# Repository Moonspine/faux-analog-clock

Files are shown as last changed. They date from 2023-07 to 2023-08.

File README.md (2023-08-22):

# Faux Analog Clock

An analog clock composed entirely of LEDs

The build should be fairly self-explanatory. A KiCad 6 schematic and board layout are included in `Board\`  
Additionally, `Board\Faux Analog Clock Gerber.zip` is a ready-to-go Gerber plot of the board which can be sent directly to the PCB manufacturer of your choice.  
LED resistor values are mere suggestions, and you should experiment on a breadboard to see what works well with your chosen LEDs.  

The following photos show the clock operating with its "Fill 2" (F2) display mode active:  
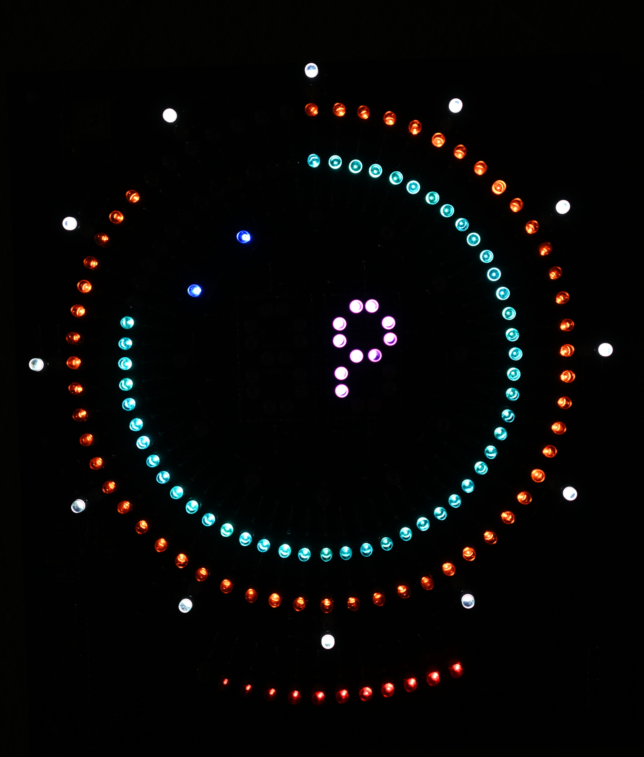
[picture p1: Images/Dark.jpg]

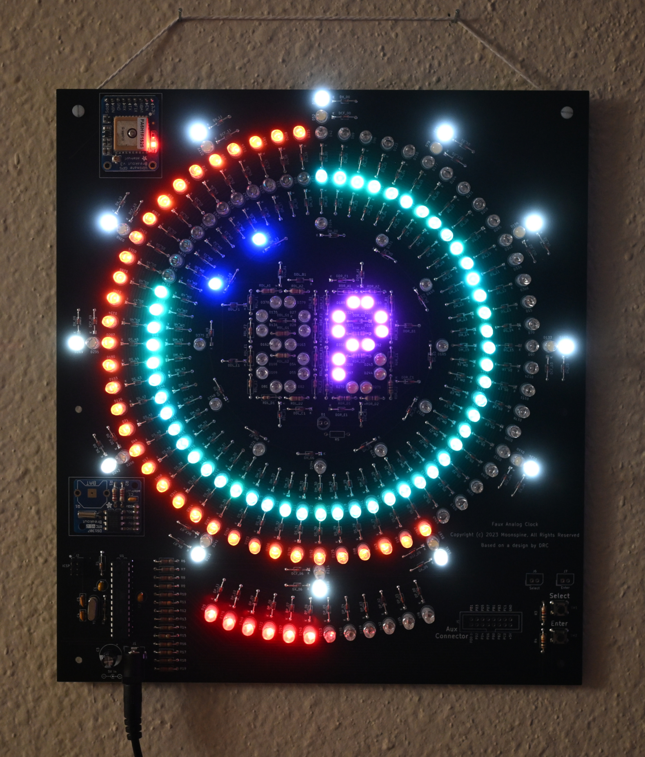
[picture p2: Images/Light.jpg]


# Debugging the build

In order to facilitate easier debugging during the build process, two LED tests are easily accessible on startup.  

If you press and hold "Select" as you turn the clock on, it will boot in "LED test 1" mode.  
This mode displays all LEDs at full brightness to help track down bad solder joints, backwards diodes, etc.  
This test mode is accessible via the utilities menu after startup. Press any key to resume the normal boot sequence.  

If you press and hold "Enter" as you turn the clock on, it will boot in "LED test 2" mode.  
This mode displays each LED in sequence. This is useful for tracking down solder bridges and confirming proper clock operation.  
This test mode is also accessible via the utilities menu after startup. Press any key to resume the normal boot sequence.  

# Using the menu

Press "Select" or "Enter" to enter the menu.  
Subsequent presses of "Select" will advance to different menu options.  
Pressing "Enter" will choose a menu option (either changing a setting or opening a submenu.)  
Pressing and holding "Select" for the amount of time defined by MENU_BACK_BUTTON_LONG_PRESS_MS will return to the previous menu (or close the menu if at the top menu.)  
If no buttons are pressed for MENU_TIMEOUT_MS milliseconds, the menu will close on its own.

## Main menu options
- tZ (72) = Timezone
- dS (d5) = Daylight Saving Time
- FE (FE) = Face effects (Clock face ring effects)
- Fd (Fd) = Fade effects
- br (br) = Brightness
- nb (nb) = Night brightness (multiplied by brightness)
- dY (d4) = Display mode
- Pd (Pd) = Pendulum period
- UT (U7) = Utilities

## Timezone menu

In this menu, you can select the timezone offset of the clock, in whole hour increments.  
These values are displayed in hexadecimal (sorry, 7-segment displays) ranging from "-C" (-12 hours) to "E" (+14 hours)

## Daylight Saving Time menu

In this menu, you can set whether DST is in effect ("Y") or not ("n")

## Face Effects menu

This menu controls the face edge lighting.
- "on" = Face effects are turned on (fading between inner and outer at sunrise/sunset)
- "ou" = Face effects are turned off, always light outer clock face ring
- "in" = Face effects are turned off, always light inner clock face ring
- "bo" = Face effects are turned off, always light both clock face rings

## Fade Effects menu

This menu turns the LED intensity fade effects on ("Y") or off ("n")

## Brightness menu

This menu controls overall clock LED brightness from 1 (dimmest) to 10 (brightest).

## Night Brightness menu

This menu controls overall clock LED brightness at night (from 6 PM to 6 AM) from 1 (dimmest) to 10 (brightest).  
This value is multiplied by the overall clock brightness, making it effectively a scalar for clock brightness that's only applied at night.

## Display mode menu

This menu allows you to select between different clock face display modes.
- "An" = Analog mode. This is the classic analog clock face, showing one LED for hours, one for minutes, and one for seconds.
- "bn" = Binary mode. This mode displays H/M/S in binary. The LSb is at 12 o'clock, and the bits are displayed in clockwise order from there. The hours use 3 LEDs per bit (displaying a 4-bit number in total), and the minutes and seconds each use 10 LEDs per bit (displaying a 6-bit number).
- "F1" = Fill mode 1. This mode fills the hour/minute/second rings as time progresses, clearing them at the turn of the minute/hour.
- "F2" = Fill mode 2. This mode fills the hour/minute/second rings on even minutes/hours/AM (respectively), and empties the rings on odd mintes/hours/PM.
- "In" = Inverted analog mode. This is the same as analog move, except that the LEDs are inverted.

## Pendulum period menu

This menu allows you to set the period of the pendulum.
- "FA" = Fast (1 second)
- "SL" = Slow (2 seconds)

## Utilities menu

This menu includes some useful utilities for testing your clock build.
- "RS" ("r5") = Reset the current time using the GPS
- "L1"        = Run LED test 1 (light all LEDs at max intensity) (press any button to end)
- "L2"        = Run LED test 2 (light LEDs at max intensity sequentially) (press any button to end)

# Customizing the clock

## Faux_Analog_Clock.ino

At the top of `Firmware/Faux_Analog_Clock/Faux_Analog_Clock.ino`, you can find many constants defined which alter the behavior of the clock.

You can change the fade animation rate by modifying variables in the "Animation timing variables" section.
- CLOCK_ANIM_*_FADE_TIME = The number of microseconds between each time the LEDs fade by 1 unit of intensity (255 is the max LED intensity)

Menu behavior can be configured as well:
- MENU_TIMEOUT_MS                = The number of milliseconds until the menu auto-closes after the last button press.
- MENU_BACK_BUTTON_LONG_PRESS_MS = The number of milliseconds the user must hold the "Select" button to return to the previous menu.

You can also change how often the GPS is used to set the RTC:
- TIMEKEEPER_GPS_TIME_SET_INTERVAL_SECONDS = Seconds in between time resets.

## ClockFace.h

FACE_INNER_HOURLY_BRIGHTNESS and FACE_OUTER_HOURLY_BRIGHTNESS define the brightness of the inner and outer edge rings on a per-hour basis.  
The first entry in each array is the brightness at midnight (hour 0), and the rest of the entries count up from there (1 AM, 2 AM, etc.)

## Pendulum.h
PENDULUM_LED_INDEX contains the LED indices of the pendulum for each individual millisecond following a second tick.  
The default pattern is a sinusoidal pendulum pattern that starts in the center and swings right then left.

## Timekeeper.h

In `Firmware/Faux_Analog_Clock/Timekeeper.h`, commenting out the following line will cause the timekeeper to use an internal millis()-based RTC rather than external RTC hardware:
```
#define USE_HARDWARE_RTC 1
```

You can also modify the amount of time that the timekeeper will attempt to get a fix before forcibly resetting the GPS (the default is 15 minutes):
```
#define GPS_RESET_TIMEOUT_MS 900000
```

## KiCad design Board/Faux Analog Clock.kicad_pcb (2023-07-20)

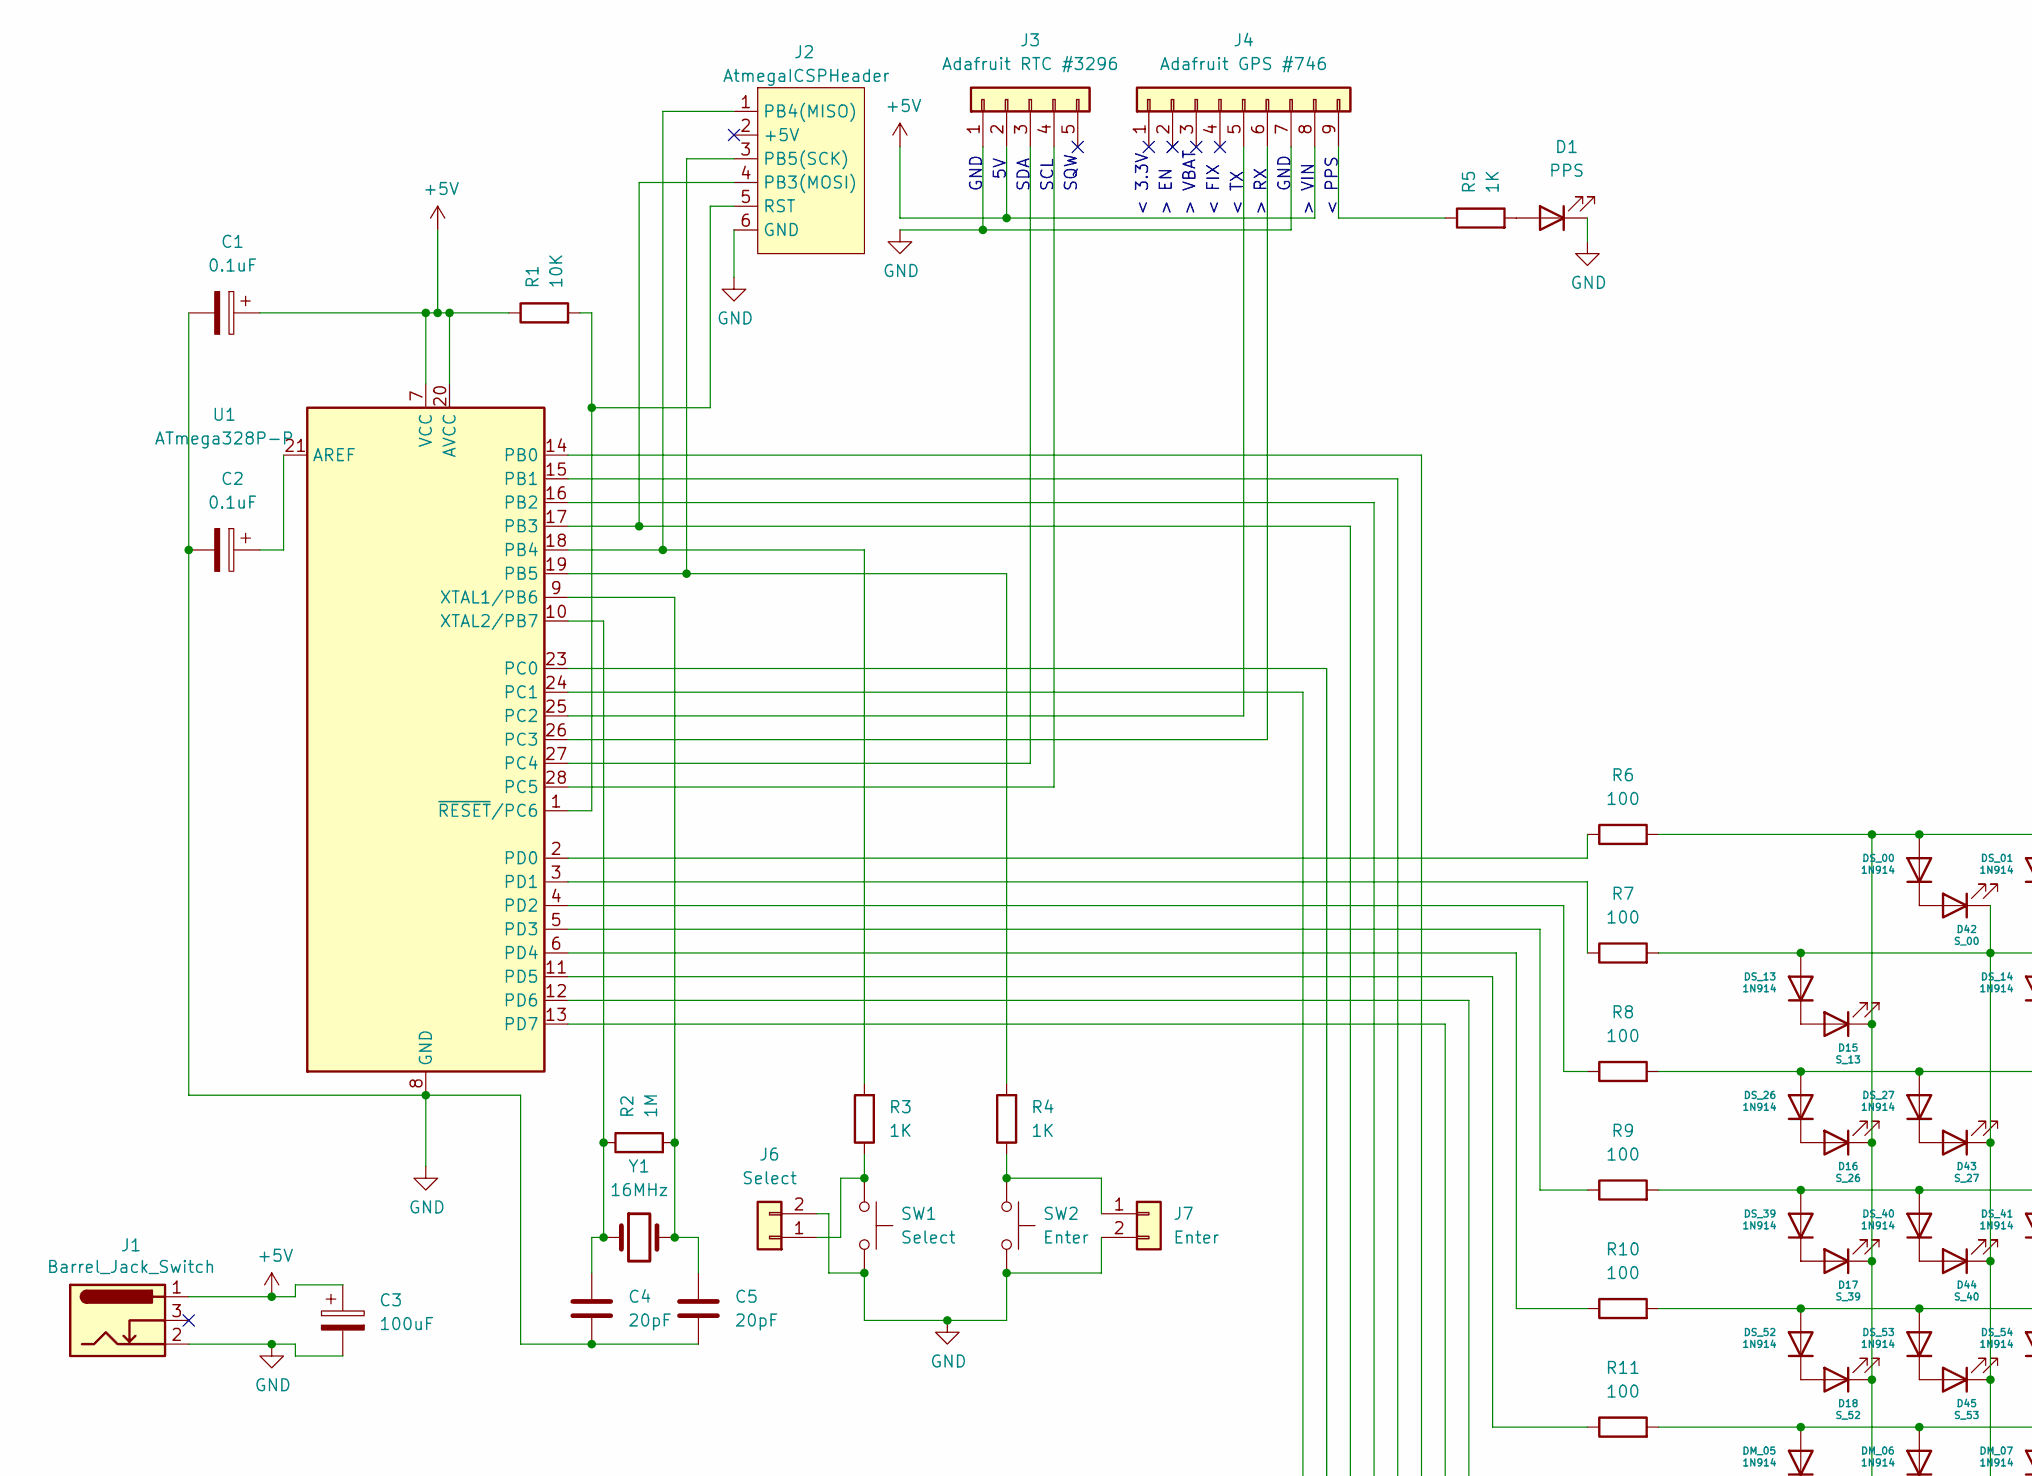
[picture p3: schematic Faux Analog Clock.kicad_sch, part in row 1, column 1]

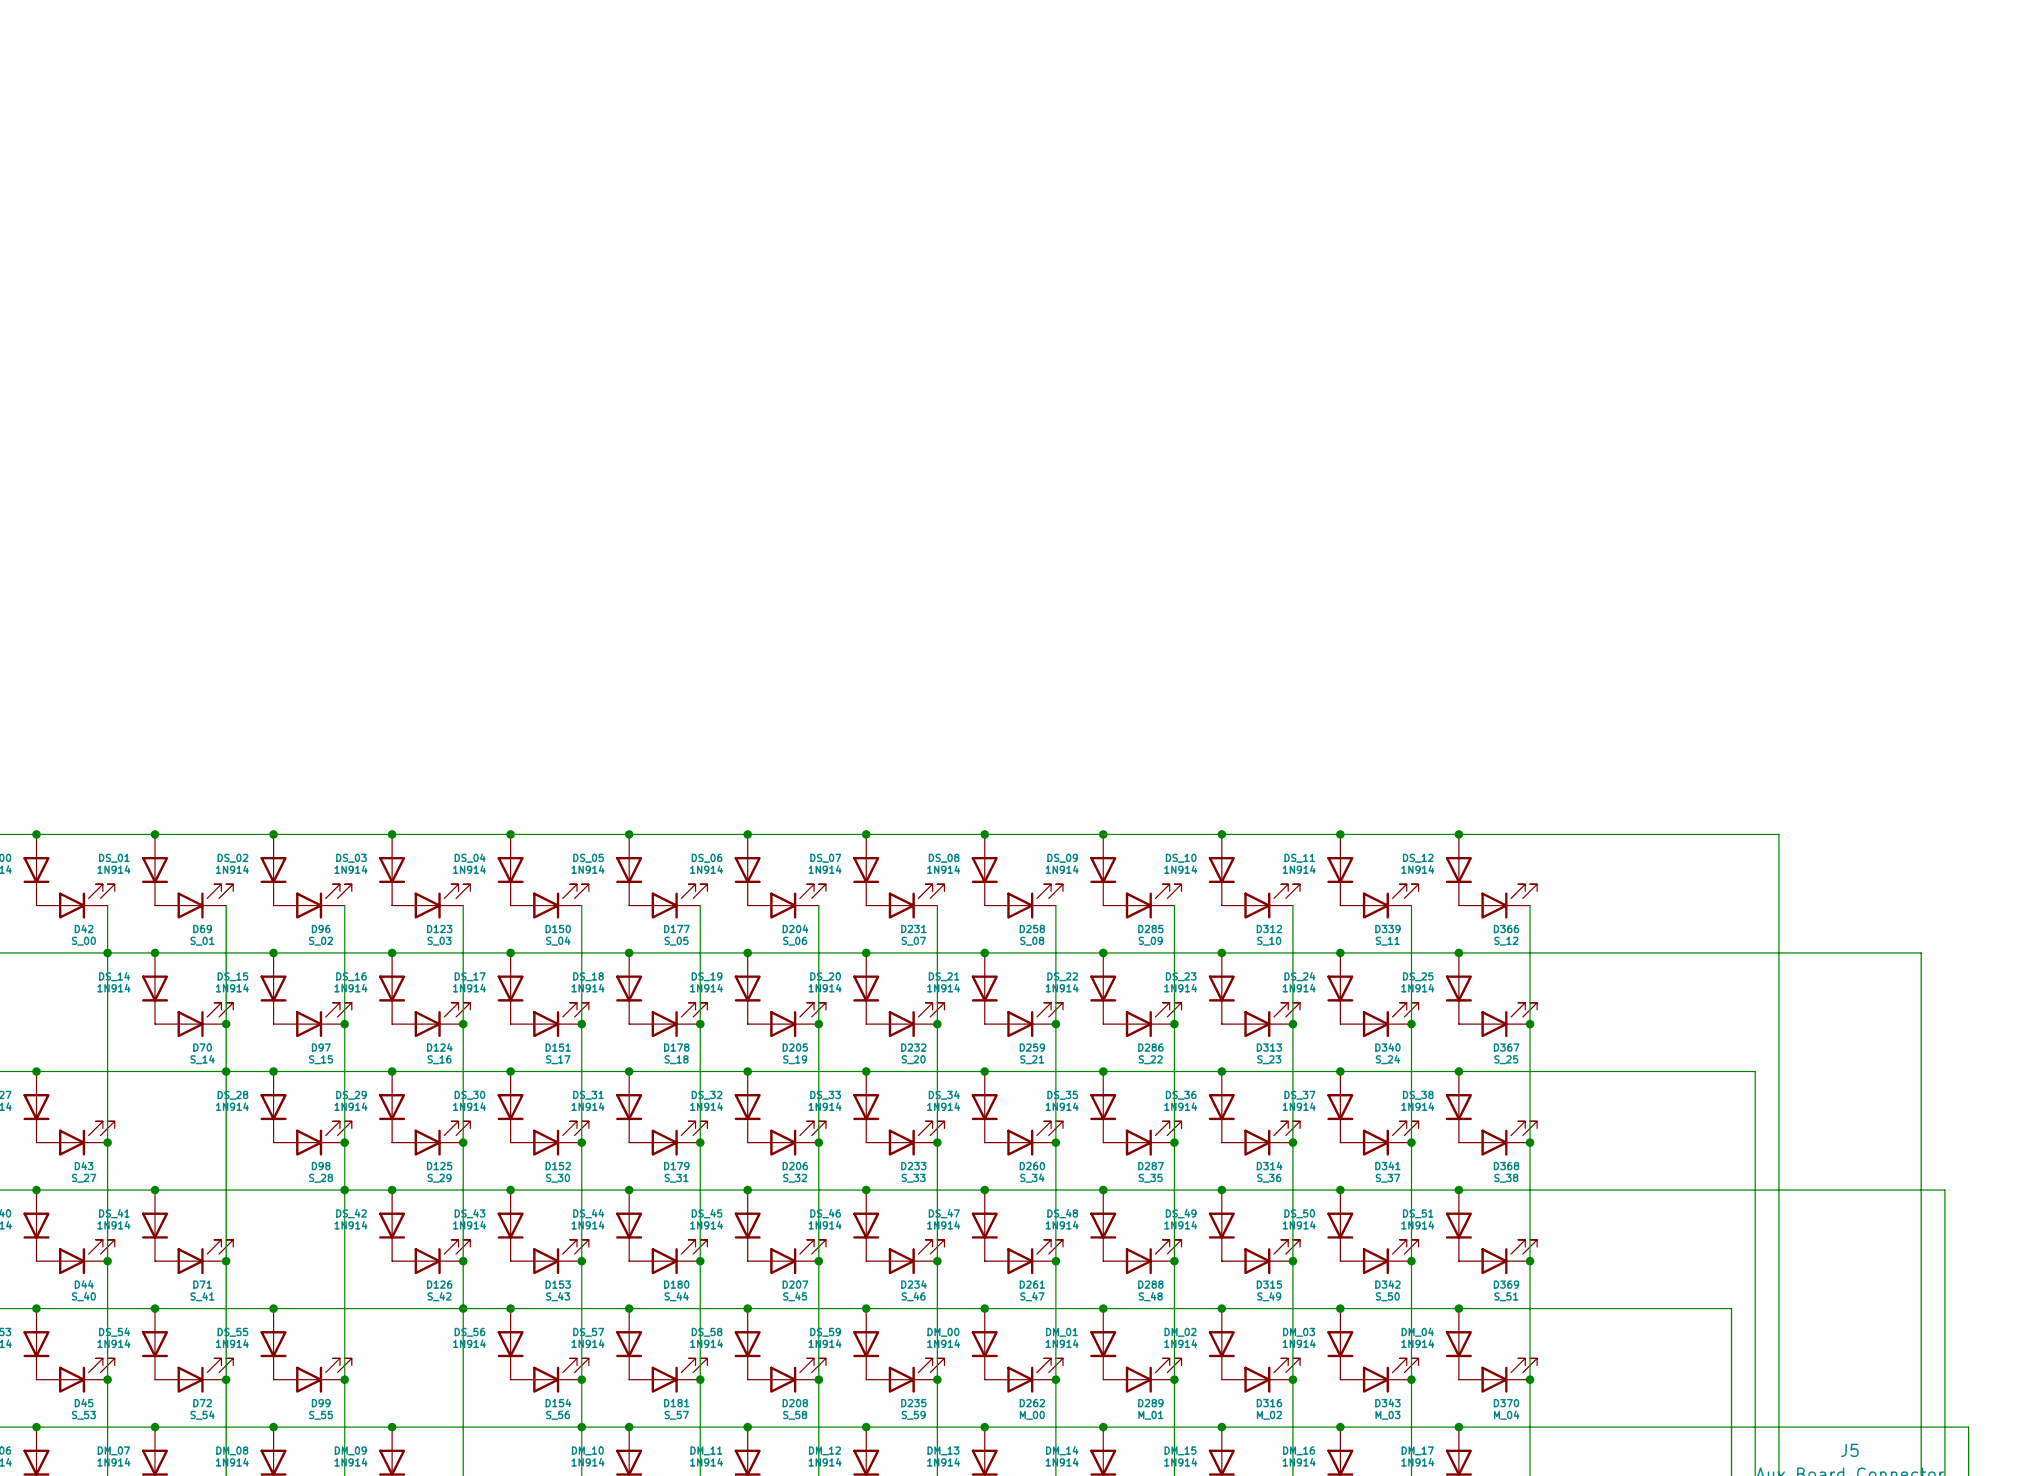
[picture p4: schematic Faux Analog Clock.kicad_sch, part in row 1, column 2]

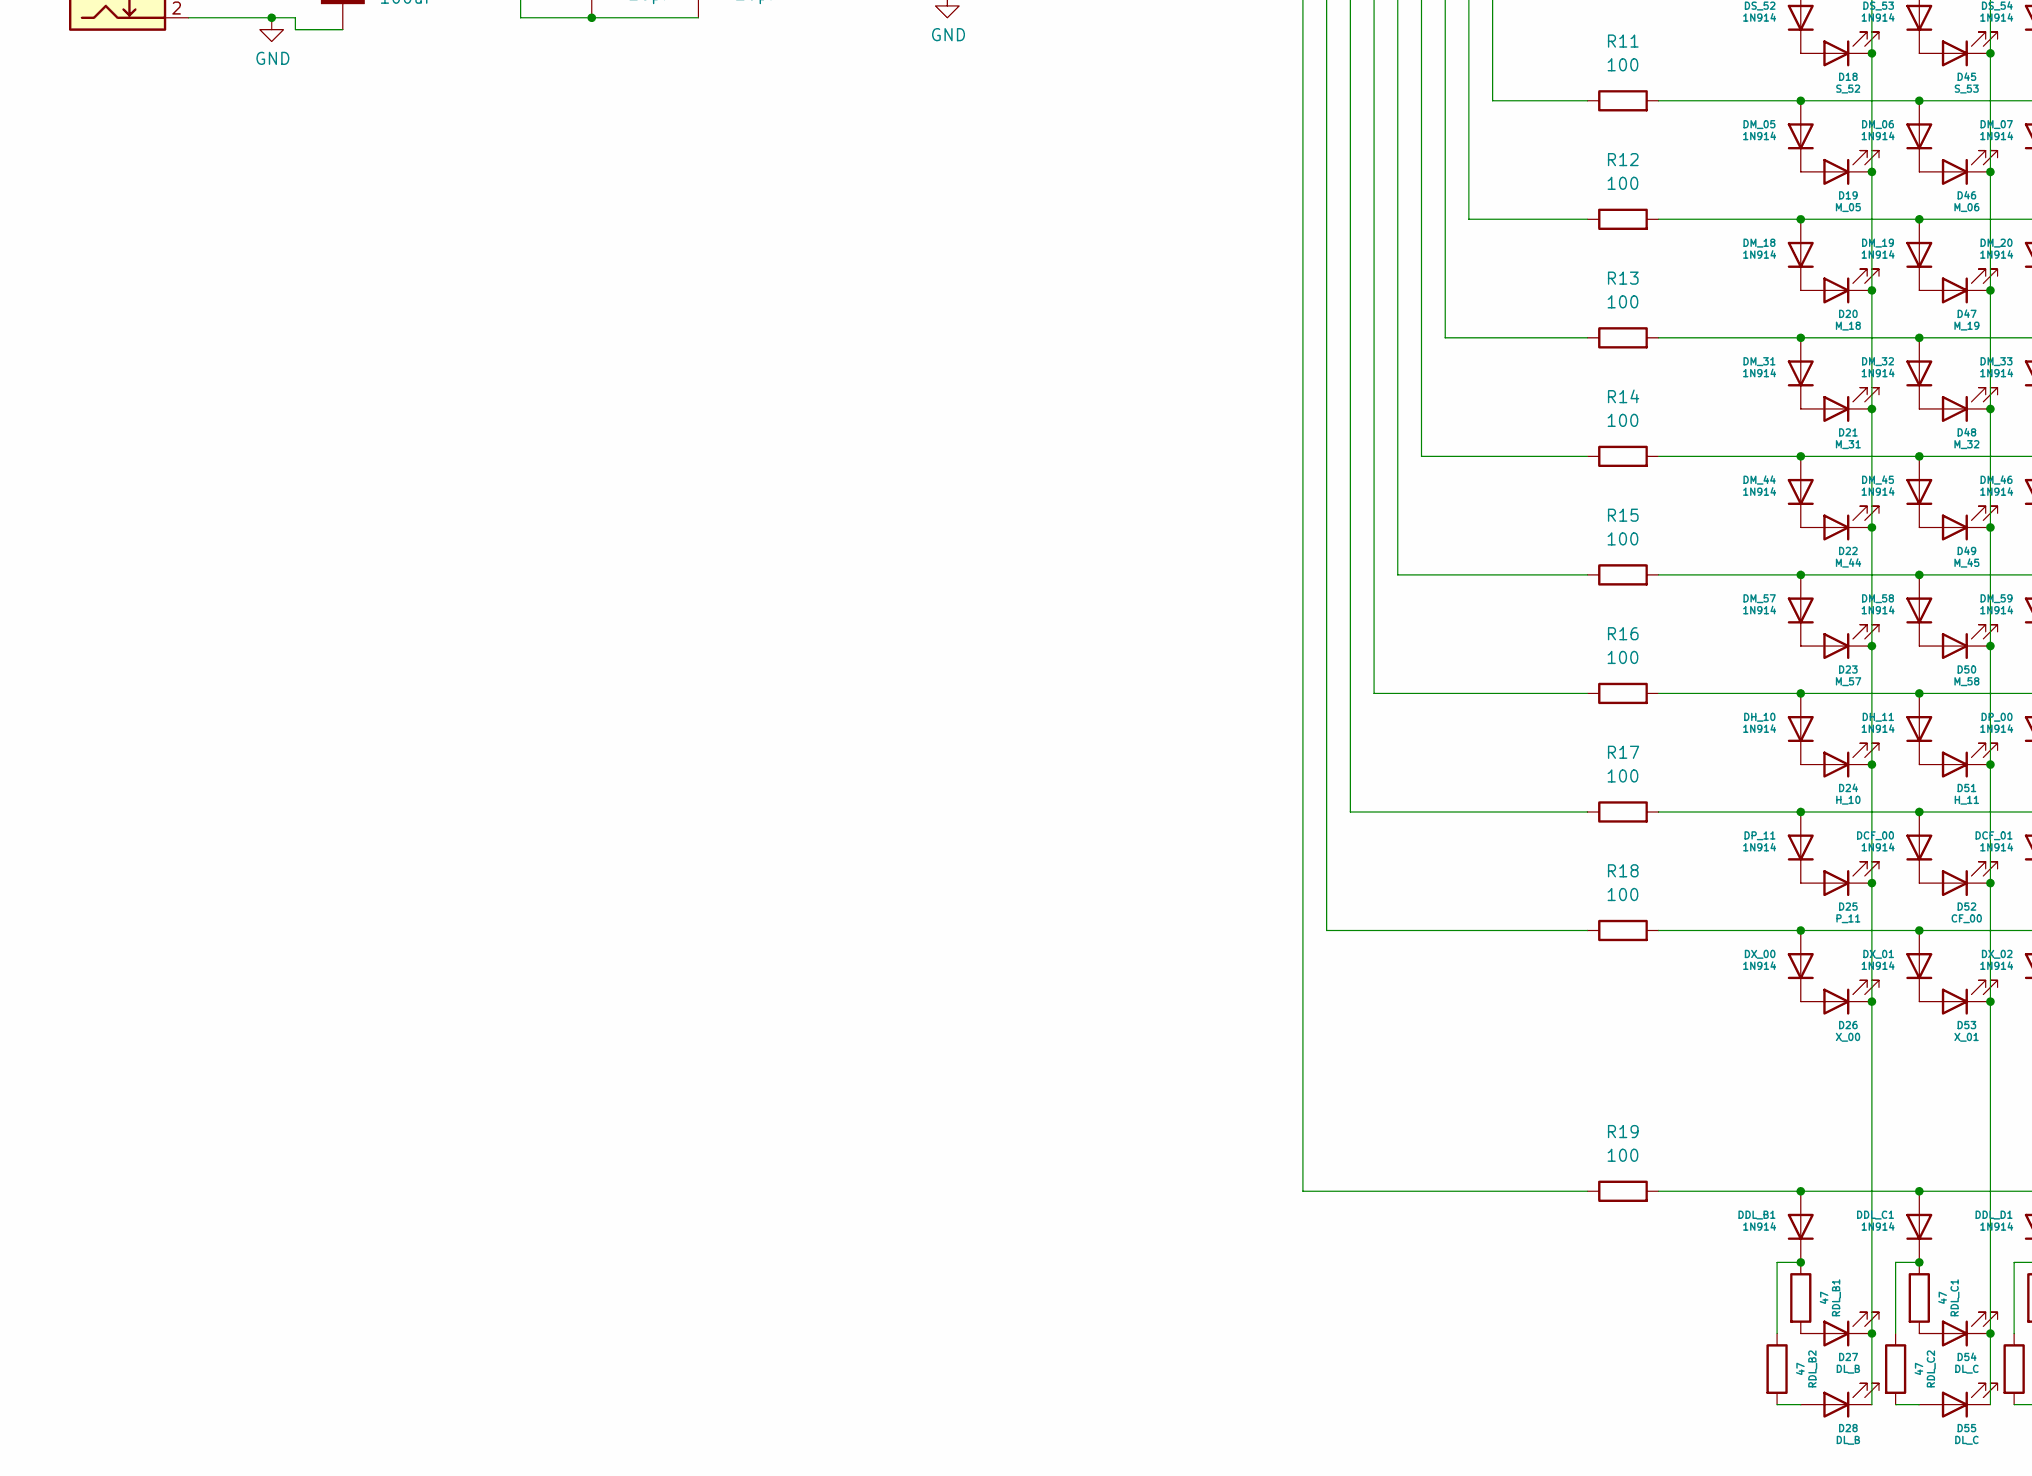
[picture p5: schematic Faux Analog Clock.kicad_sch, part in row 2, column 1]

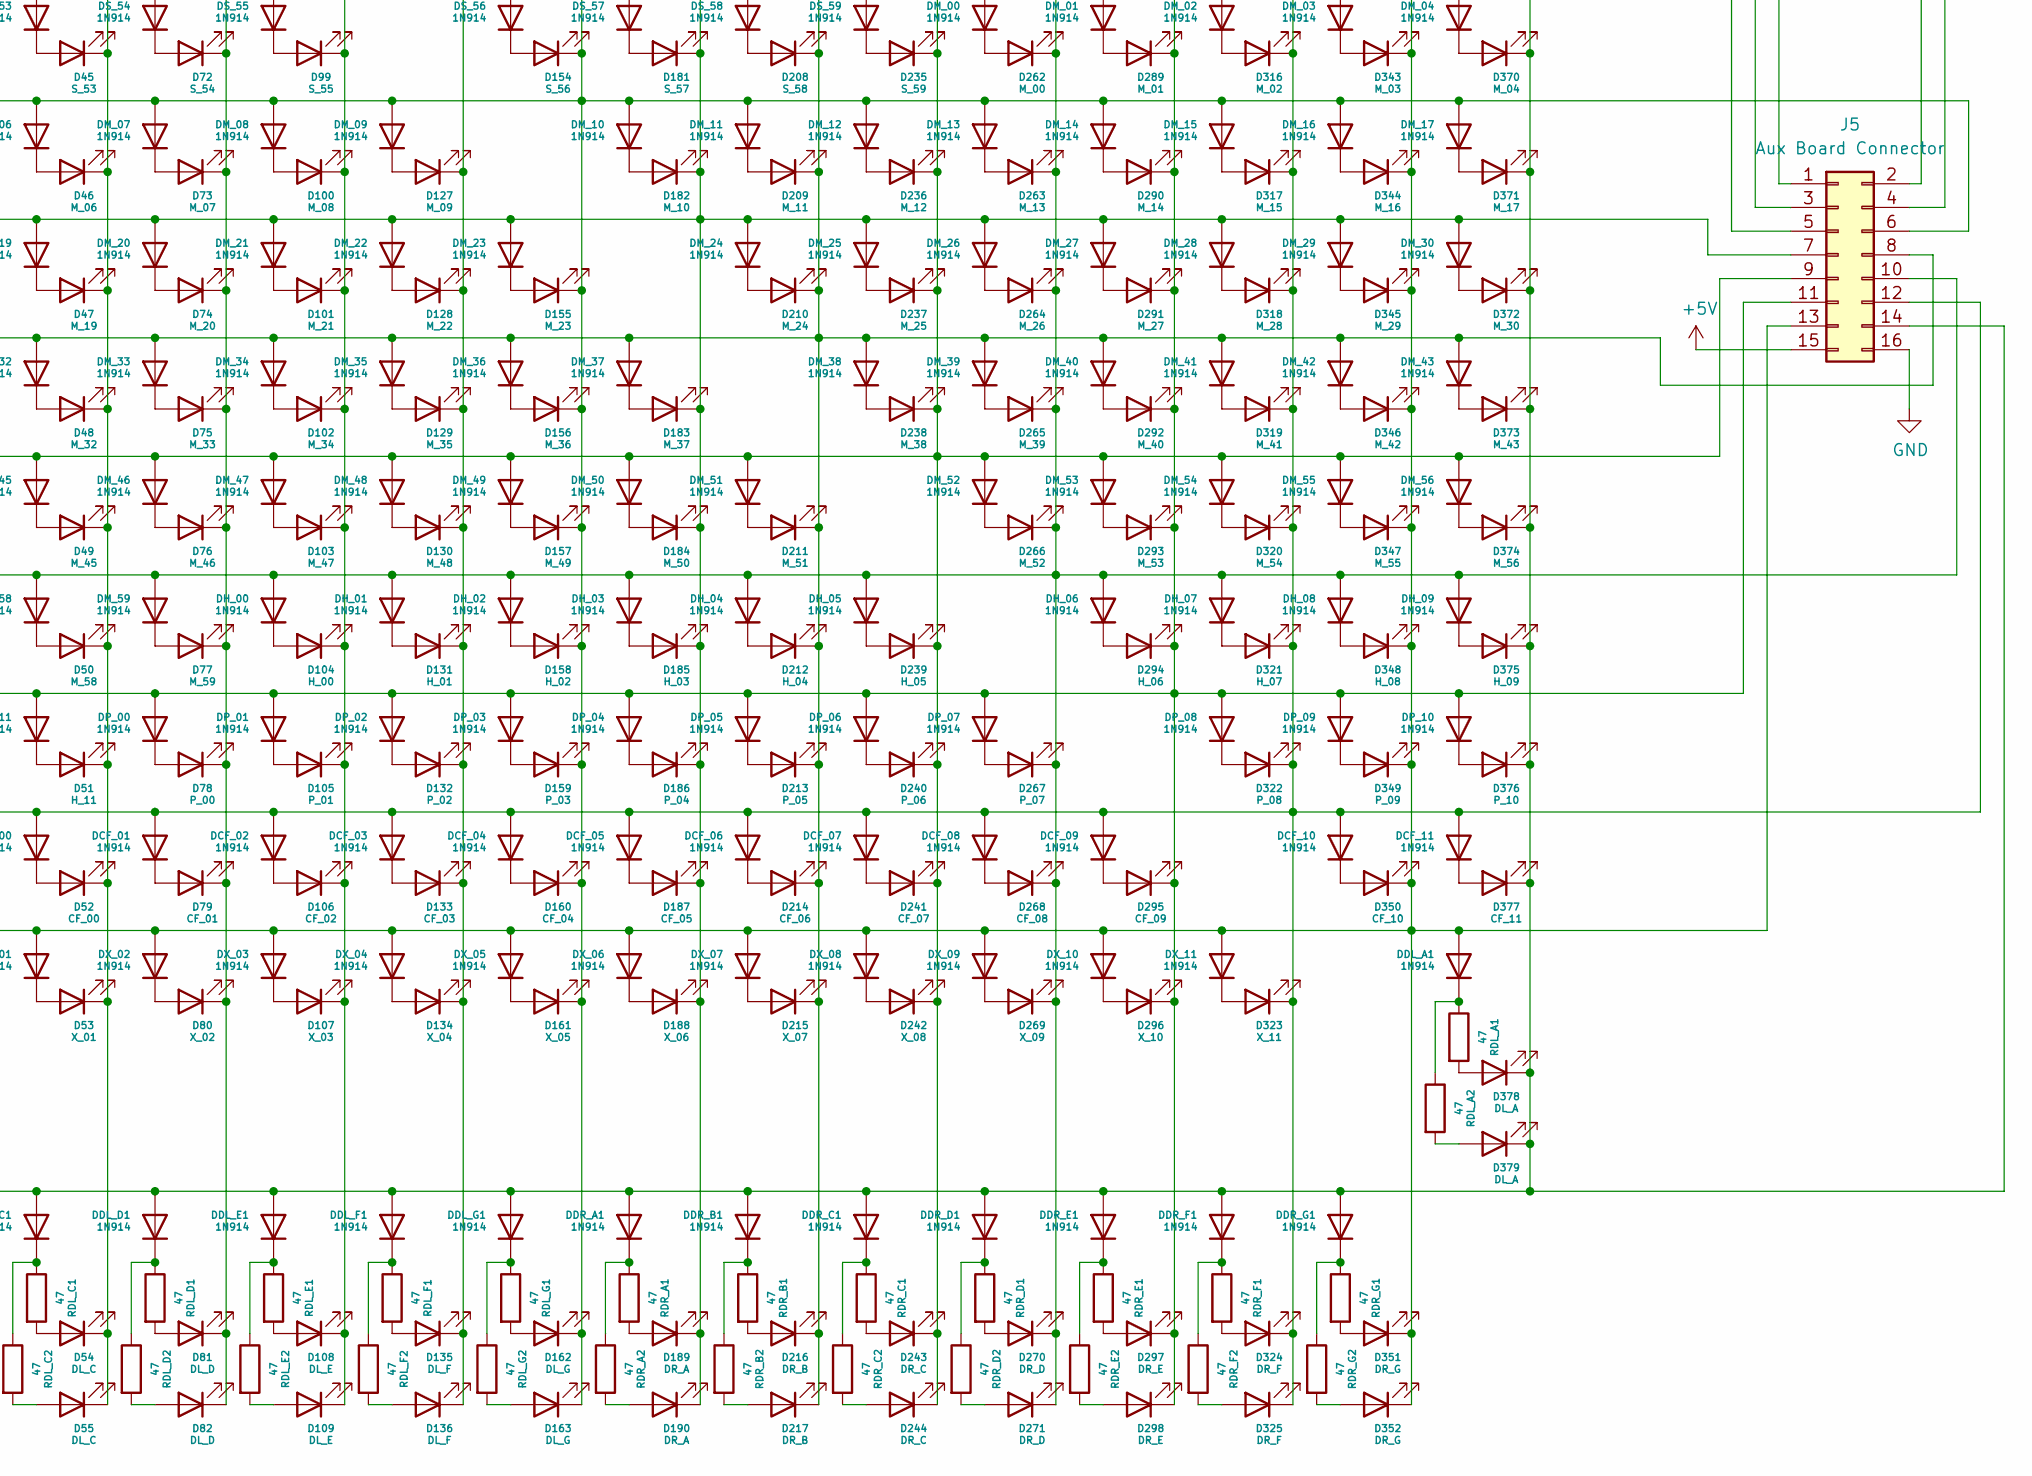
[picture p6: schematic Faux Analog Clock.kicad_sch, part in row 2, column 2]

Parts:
C1, C2: 0.1uF; CP_Radial_Tantal_D5.0mm_P2.50mm
C3: 100uF; CP_Radial_D10.0mm_P3.50mm
C4, C5: 20pF; C_Disc_D5.0mm_W2.5mm_P2.50mm
D1: PPS; LED_D5.0mm
D15: S_13; LED_D5.0mm
D16: S_26; LED_D5.0mm
D17: S_39; LED_D5.0mm
D18: S_52; LED_D5.0mm
D19: M_05; LED_D5.0mm
D20: M_18; LED_D5.0mm
D21: M_31; LED_D5.0mm
D22: M_44; LED_D5.0mm
D23: M_57; LED_D5.0mm
D24: H_10; LED_D5.0mm
D25: P_11; LED_D5.0mm
D26: X_00; LED_D5.0mm
D27, D28: DL_B; LED_D5.0mm
D42: S_00; LED_D5.0mm
D43: S_27; LED_D5.0mm
D44: S_40; LED_D5.0mm
D45: S_53; LED_D5.0mm
D46: M_06; LED_D5.0mm
D47: M_19; LED_D5.0mm
D48: M_32; LED_D5.0mm
D49: M_45; LED_D5.0mm
D50: M_58; LED_D5.0mm
D51: H_11; LED_D5.0mm
D52: CF_00; LED_D5.0mm
D53: X_01; LED_D5.0mm
D54, D55: DL_C; LED_D5.0mm
D69: S_01; LED_D5.0mm
D70: S_14; LED_D5.0mm
D71: S_41; LED_D5.0mm
D72: S_54; LED_D5.0mm
D73: M_07; LED_D5.0mm
D74: M_20; LED_D5.0mm
D75: M_33; LED_D5.0mm
D76: M_46; LED_D5.0mm
D77: M_59; LED_D5.0mm
D78: P_00; LED_D5.0mm
D79: CF_01; LED_D5.0mm
D80: X_02; LED_D5.0mm
D81, D82: DL_D; LED_D5.0mm
D96: S_02; LED_D5.0mm
D97: S_15; LED_D5.0mm
D98: S_28; LED_D5.0mm
D99: S_55; LED_D5.0mm
D100: M_08; LED_D5.0mm
D101: M_21; LED_D5.0mm
D102: M_34; LED_D5.0mm
D103: M_47; LED_D5.0mm
D104: H_00; LED_D5.0mm
D105: P_01; LED_D5.0mm
D106: CF_02; LED_D5.0mm
D107: X_03; LED_D5.0mm
D108, D109: DL_E; LED_D5.0mm
D123: S_03; LED_D5.0mm
D124: S_16; LED_D5.0mm
D125: S_29; LED_D5.0mm
D126: S_42; LED_D5.0mm
D127: M_09; LED_D5.0mm
D128: M_22; LED_D5.0mm
D129: M_35; LED_D5.0mm
D130: M_48; LED_D5.0mm
D131: H_01; LED_D5.0mm
D132: P_02; LED_D5.0mm
D133: CF_03; LED_D5.0mm
D134: X_04; LED_D5.0mm
D135, D136: DL_F; LED_D5.0mm
D150: S_04; LED_D5.0mm
D151: S_17; LED_D5.0mm
D152: S_30; LED_D5.0mm
D153: S_43; LED_D5.0mm
D154: S_56; LED_D5.0mm
D155: M_23; LED_D5.0mm
D156: M_36; LED_D5.0mm
D157: M_49; LED_D5.0mm
D158: H_02; LED_D5.0mm
D159: P_03; LED_D5.0mm
D160: CF_04; LED_D5.0mm
D161: X_05; LED_D5.0mm
D162, D163: DL_G; LED_D5.0mm
D177: S_05; LED_D5.0mm
D178: S_18; LED_D5.0mm
D179: S_31; LED_D5.0mm
D180: S_44; LED_D5.0mm
D181: S_57; LED_D5.0mm
D182: M_10; LED_D5.0mm
D183: M_37; LED_D5.0mm
D184: M_50; LED_D5.0mm
D185: H_03; LED_D5.0mm
D186: P_04; LED_D5.0mm
D187: CF_05; LED_D5.0mm
D188: X_06; LED_D5.0mm
D189, D190: DR_A; LED_D5.0mm
D204: S_06; LED_D5.0mm
D205: S_19; LED_D5.0mm
D206: S_32; LED_D5.0mm
D207: S_45; LED_D5.0mm
D208: S_58; LED_D5.0mm
D209: M_11; LED_D5.0mm
D210: M_24; LED_D5.0mm
D211: M_51; LED_D5.0mm
D212: H_04; LED_D5.0mm
D213: P_05; LED_D5.0mm
D214: CF_06; LED_D5.0mm
D215: X_07; LED_D5.0mm
D216, D217: DR_B; LED_D5.0mm
D231: S_07; LED_D5.0mm
D232: S_20; LED_D5.0mm
D233: S_33; LED_D5.0mm
D234: S_46; LED_D5.0mm
D235: S_59; LED_D5.0mm
D236: M_12; LED_D5.0mm
D237: M_25; LED_D5.0mm
D238: M_38; LED_D5.0mm
D239: H_05; LED_D5.0mm
D240: P_06; LED_D5.0mm
D241: CF_07; LED_D5.0mm
D242: X_08; LED_D5.0mm
D243, D244: DR_C; LED_D5.0mm
D258: S_08; LED_D5.0mm
D259: S_21; LED_D5.0mm
D260: S_34; LED_D5.0mm
D261: S_47; LED_D5.0mm
D262: M_00; LED_D5.0mm
D263: M_13; LED_D5.0mm
D264: M_26; LED_D5.0mm
D265: M_39; LED_D5.0mm
D266: M_52; LED_D5.0mm
D267: P_07; LED_D5.0mm
D268: CF_08; LED_D5.0mm
D269: X_09; LED_D5.0mm
D270, D271: DR_D; LED_D5.0mm
D285: S_09; LED_D5.0mm
D286: S_22; LED_D5.0mm
D287: S_35; LED_D5.0mm
D288: S_48; LED_D5.0mm
D289: M_01; LED_D5.0mm
D290: M_14; LED_D5.0mm
D291: M_27; LED_D5.0mm
D292: M_40; LED_D5.0mm
D293: M_53; LED_D5.0mm
D294: H_06; LED_D5.0mm
D295: CF_09; LED_D5.0mm
D296: X_10; LED_D5.0mm
D297, D298: DR_E; LED_D5.0mm
D312: S_10; LED_D5.0mm
D313: S_23; LED_D5.0mm
D314: S_36; LED_D5.0mm
D315: S_49; LED_D5.0mm
D316: M_02; LED_D5.0mm
D317: M_15; LED_D5.0mm
D318: M_28; LED_D5.0mm
D319: M_41; LED_D5.0mm
D320: M_54; LED_D5.0mm
D321: H_07; LED_D5.0mm
D322: P_08; LED_D5.0mm
D323: X_11; LED_D5.0mm
D324, D325: DR_F; LED_D5.0mm
D339: S_11; LED_D5.0mm
D340: S_24; LED_D5.0mm
D341: S_37; LED_D5.0mm
D342: S_50; LED_D5.0mm
D343: M_03; LED_D5.0mm
D344: M_16; LED_D5.0mm
D345: M_29; LED_D5.0mm
D346: M_42; LED_D5.0mm
D347: M_55; LED_D5.0mm
D348: H_08; LED_D5.0mm
D349: P_09; LED_D5.0mm
D350: CF_10; LED_D5.0mm
D351, D352: DR_G; LED_D5.0mm
D366: S_12; LED_D5.0mm
D367: S_25; LED_D5.0mm
D368: S_38; LED_D5.0mm
D369: S_51; LED_D5.0mm
D370: M_04; LED_D5.0mm
D371: M_17; LED_D5.0mm
D372: M_30; LED_D5.0mm
D373: M_43; LED_D5.0mm
D374: M_56; LED_D5.0mm
D375: H_09; LED_D5.0mm
D376: P_10; LED_D5.0mm
D377: CF_11; LED_D5.0mm
D378, D379: DL_A; LED_D5.0mm
DCF_00, DCF_01, DCF_02, DCF_03, DCF_04, DCF_05, DCF_06, DCF_07, DCF_08, DCF_09, DCF_10, DCF_11: 1N914; D_DO-34_SOD68_P10.16mm_Horizontal
DDL_A1: 1N914; D_DO-34_SOD68_P10.16mm_Horizontal
DDL_B1: 1N914; D_DO-34_SOD68_P10.16mm_Horizontal
DDL_C1: 1N914; D_DO-34_SOD68_P10.16mm_Horizontal
DDL_D1: 1N914; D_DO-34_SOD68_P10.16mm_Horizontal
DDL_E1: 1N914; D_DO-34_SOD68_P10.16mm_Horizontal
DDL_F1: 1N914; D_DO-34_SOD68_P10.16mm_Horizontal
DDL_G1: 1N914; D_DO-34_SOD68_P10.16mm_Horizontal
DDR_A1: 1N914; D_DO-34_SOD68_P10.16mm_Horizontal
DDR_B1: 1N914; D_DO-34_SOD68_P10.16mm_Horizontal
DDR_C1: 1N914; D_DO-34_SOD68_P10.16mm_Horizontal
DDR_D1: 1N914; D_DO-34_SOD68_P10.16mm_Horizontal
DDR_E1: 1N914; D_DO-34_SOD68_P10.16mm_Horizontal
DDR_F1: 1N914; D_DO-34_SOD68_P10.16mm_Horizontal
DDR_G1: 1N914; D_DO-34_SOD68_P10.16mm_Horizontal
DH_00, DH_01, DH_02, DH_03, DH_04, DH_05, DH_06, DH_07, DH_08, DH_09, DH_10, DH_11: 1N914; D_DO-34_SOD68_P10.16mm_Horizontal
DM_00, DM_01, DM_02, DM_03, DM_04, DM_05, DM_06, DM_07, DM_08, DM_09, DM_10, DM_11, DM_12, DM_13, DM_14, DM_15, DM_16, DM_17, DM_18, DM_19, DM_20, DM_21, DM_22, DM_23, DM_24, DM_25, DM_26, DM_27, DM_28, DM_29, DM_30, DM_31, DM_32, DM_33, DM_34, DM_35, DM_36, DM_37, DM_38, DM_39, DM_40, DM_41, DM_42, DM_43, DM_44, DM_45, DM_46, DM_47, DM_48, DM_49, DM_50, DM_51, DM_52, DM_53, DM_54, DM_55, DM_56, DM_57, DM_58, DM_59: 1N914; D_DO-34_SOD68_P10.16mm_Horizontal
DP_00, DP_01, DP_02, DP_03, DP_04, DP_05, DP_06, DP_07, DP_08, DP_09, DP_10, DP_11: 1N914; D_DO-34_SOD68_P10.16mm_Horizontal
DS_00, DS_01, DS_02, DS_03, DS_04, DS_05, DS_06, DS_07, DS_08, DS_09, DS_10, DS_11, DS_12, DS_13, DS_14, DS_15, DS_16, DS_17, DS_18, DS_19, DS_20, DS_21, DS_22, DS_23, DS_24, DS_25, DS_26, DS_27, DS_28, DS_29, DS_30, DS_31, DS_32, DS_33, DS_34, DS_35, DS_36, DS_37, DS_38, DS_39, DS_40, DS_41, DS_42, DS_43, DS_44, DS_45, DS_46, DS_47, DS_48, DS_49, DS_50, DS_51, DS_52, DS_53, DS_54, DS_55, DS_56, DS_57, DS_58, DS_59: 1N914; D_DO-34_SOD68_P10.16mm_Horizontal
DX_00, DX_01, DX_02, DX_03, DX_04, DX_05, DX_06, DX_07, DX_08, DX_09, DX_10, DX_11: 1N914; D_DO-34_SOD68_P10.16mm_Horizontal
J1: Barrel_Jack_Switch; BarrelJack_Wuerth_6941xx301002
J2: AtmegaICSPHeader; PinHeader_2x03_P2.54mm_Vertical
J3: Adafruit RTC #3296; PinHeader_1x05_P2.54mm_Vertical
J4: Adafruit GPS #746; PinHeader_1x09_P2.54mm_Vertical
J5: Aux Board Connector; IDC-Header_2x08_P2.54mm_Vertical
J6: Select; Molex_SPOX_5267-02A_1x02_P2.50mm_Vertical
J7: Enter; Molex_SPOX_5267-02A_1x02_P2.50mm_Vertical
R1: 10K; R_Axial_DIN0207_L6.3mm_D2.5mm_P10.16mm_Horizontal
R2: 1M; R_Axial_DIN0207_L6.3mm_D2.5mm_P10.16mm_Horizontal
R3, R4, R5: 1K; R_Axial_DIN0207_L6.3mm_D2.5mm_P10.16mm_Horizontal
R6, R7, R8, R9, R10, R11, R12, R13, R14, R15, R16, R17, R18, R19: 100; R_Axial_DIN0207_L6.3mm_D2.5mm_P10.16mm_Horizontal
RDL_A1, RDL_A2: 47; R_Axial_DIN0207_L6.3mm_D2.5mm_P10.16mm_Horizontal
RDL_B1, RDL_B2: 47; R_Axial_DIN0207_L6.3mm_D2.5mm_P10.16mm_Horizontal
RDL_C1, RDL_C2: 47; R_Axial_DIN0207_L6.3mm_D2.5mm_P10.16mm_Horizontal
RDL_D1, RDL_D2: 47; R_Axial_DIN0207_L6.3mm_D2.5mm_P10.16mm_Horizontal
RDL_E1, RDL_E2: 47; R_Axial_DIN0207_L6.3mm_D2.5mm_P10.16mm_Horizontal
RDL_F1, RDL_F2: 47; R_Axial_DIN0207_L6.3mm_D2.5mm_P10.16mm_Horizontal
RDL_G1, RDL_G2: 47; R_Axial_DIN0207_L6.3mm_D2.5mm_P10.16mm_Horizontal
RDR_A1, RDR_A2: 47; R_Axial_DIN0207_L6.3mm_D2.5mm_P10.16mm_Horizontal
RDR_B1, RDR_B2: 47; R_Axial_DIN0207_L6.3mm_D2.5mm_P10.16mm_Horizontal
RDR_C1, RDR_C2: 47; R_Axial_DIN0207_L6.3mm_D2.5mm_P10.16mm_Horizontal
RDR_D1, RDR_D2: 47; R_Axial_DIN0207_L6.3mm_D2.5mm_P10.16mm_Horizontal
RDR_E1, RDR_E2: 47; R_Axial_DIN0207_L6.3mm_D2.5mm_P10.16mm_Horizontal
RDR_F1, RDR_F2: 47; R_Axial_DIN0207_L6.3mm_D2.5mm_P10.16mm_Horizontal
RDR_G1, RDR_G2: 47; R_Axial_DIN0207_L6.3mm_D2.5mm_P10.16mm_Horizontal
SW1: Select; SW_PUSH_6mm
SW2: Enter; SW_PUSH_6mm
U1: ATmega328P-P; DIP-28_W7.62mm_LongPads
Y1: 16MHz; Crystal_HC49-U_Vertical

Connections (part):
+5V: C1.1, C3.1, J1.1, J3.2, J4.8, J5.15, R1.1, U1.7 (VCC), U1.20 (AVCC)
GND: C1.2, C2.2, C3.2, C4.2, C5.2, D1.1 (K), J1.2, J2.6 (GND), J3.1, J4.7, J5.16, J6.2, J7.2, SW1.2, SW2.2, U1.8 (GND), U1.22 (GND)
unnamed: C2.1, U1.21 (AREF)
unnamed: C4.1, R2.1, U1.10 (XTAL2/PB7), Y1.1
unnamed: C5.1, R2.2, U1.9 (XTAL1/PB6), Y1.2
unnamed: D1.2 (A), R5.2
unnamed: D15.1 (K), D16.1 (K), D17.1 (K), D18.1 (K), D19.1 (K), D20.1 (K), D21.1 (K), D22.1 (K), D23.1 (K), D24.1 (K), D25.1 (K), D26.1 (K), D27.1 (K), D28.1 (K), DS_00.2 (A), DS_01.2 (A), DS_02.2 (A), DS_03.2 (A), DS_04.2 (A), DS_05.2 (A), DS_06.2 (A), DS_07.2 (A), DS_08.2 (A), DS_09.2 (A), DS_10.2 (A), DS_11.2 (A), DS_12.2 (A), J5.1, R6.2
unnamed: D15.2 (A), DS_13.1 (K)
unnamed: D16.2 (A), DS_26.1 (K)
unnamed: D17.2 (A), DS_39.1 (K)
unnamed: D18.2 (A), DS_52.1 (K)
unnamed: D19.2 (A), DM_05.1 (K)
unnamed: D20.2 (A), DM_18.1 (K)
unnamed: D21.2 (A), DM_31.1 (K)
unnamed: D22.2 (A), DM_44.1 (K)
unnamed: D23.2 (A), DM_57.1 (K)
unnamed: D24.2 (A), DH_10.1 (K)
unnamed: D25.2 (A), DP_11.1 (K)
unnamed: D26.2 (A), DX_00.1 (K)
unnamed: D27.2 (A), RDL_B1.2
unnamed: D28.2 (A), RDL_B2.2
unnamed: D42.1 (K), D43.1 (K), D44.1 (K), D45.1 (K), D46.1 (K), D47.1 (K), D48.1 (K), D49.1 (K), D50.1 (K), D51.1 (K), D52.1 (K), D53.1 (K), D54.1 (K), D55.1 (K), DS_13.2 (A), DS_14.2 (A), DS_15.2 (A), DS_16.2 (A), DS_17.2 (A), DS_18.2 (A), DS_19.2 (A), DS_20.2 (A), DS_21.2 (A), DS_22.2 (A), DS_23.2 (A), DS_24.2 (A), DS_25.2 (A), J5.2, R7.2
unnamed: D42.2 (A), DS_00.1 (K)
unnamed: D43.2 (A), DS_27.1 (K)
unnamed: D44.2 (A), DS_40.1 (K)
unnamed: D45.2 (A), DS_53.1 (K)
unnamed: D46.2 (A), DM_06.1 (K)
unnamed: D47.2 (A), DM_19.1 (K)
unnamed: D48.2 (A), DM_32.1 (K)
unnamed: D49.2 (A), DM_45.1 (K)
unnamed: D50.2 (A), DM_58.1 (K)
unnamed: D51.2 (A), DH_11.1 (K)
unnamed: D52.2 (A), DCF_00.1 (K)
unnamed: D53.2 (A), DX_01.1 (K)
unnamed: D54.2 (A), RDL_C1.2
unnamed: D55.2 (A), RDL_C2.2
unnamed: D69.1 (K), D70.1 (K), D71.1 (K), D72.1 (K), D73.1 (K), D74.1 (K), D75.1 (K), D76.1 (K), D77.1 (K), D78.1 (K), D79.1 (K), D80.1 (K), D81.1 (K), D82.1 (K), DS_26.2 (A), DS_27.2 (A), DS_28.2 (A), DS_29.2 (A), DS_30.2 (A), DS_31.2 (A), DS_32.2 (A), DS_33.2 (A), DS_34.2 (A), DS_35.2 (A), DS_36.2 (A), DS_37.2 (A), DS_38.2 (A), J5.3, R8.2
unnamed: D69.2 (A), DS_01.1 (K)
unnamed: D70.2 (A), DS_14.1 (K)
unnamed: D71.2 (A), DS_41.1 (K)
unnamed: D72.2 (A), DS_54.1 (K)
unnamed: D73.2 (A), DM_07.1 (K)
unnamed: D74.2 (A), DM_20.1 (K)
unnamed: D75.2 (A), DM_33.1 (K)
unnamed: D76.2 (A), DM_46.1 (K)
unnamed: D77.2 (A), DM_59.1 (K)
unnamed: D78.2 (A), DP_00.1 (K)
unnamed: D79.2 (A), DCF_01.1 (K)
unnamed: D80.2 (A), DX_02.1 (K)
unnamed: D81.2 (A), RDL_D1.2
unnamed: D82.2 (A), RDL_D2.2
unnamed: D96.2 (A), DS_02.1 (K)
unnamed: D97.2 (A), DS_15.1 (K)
unnamed: D98.2 (A), DS_28.1 (K)
unnamed: D99.2 (A), DS_55.1 (K)
unnamed: D96.1 (K), D97.1 (K), D98.1 (K), D99.1 (K), D100.1 (K), D101.1 (K), D102.1 (K), D103.1 (K), D104.1 (K), D105.1 (K), D106.1 (K), D107.1 (K), D108.1 (K), D109.1 (K), DS_39.2 (A), DS_40.2 (A), DS_41.2 (A), DS_42.2 (A), DS_43.2 (A), DS_44.2 (A), DS_45.2 (A), DS_46.2 (A), DS_47.2 (A), DS_48.2 (A), DS_49.2 (A), DS_50.2 (A), DS_51.2 (A), J5.4, R9.2
unnamed: D100.2 (A), DM_08.1 (K)
unnamed: D101.2 (A), DM_21.1 (K)
unnamed: D102.2 (A), DM_34.1 (K)
unnamed: D103.2 (A), DM_47.1 (K)
unnamed: D104.2 (A), DH_00.1 (K)
unnamed: D105.2 (A), DP_01.1 (K)
unnamed: D106.2 (A), DCF_02.1 (K)
unnamed: D107.2 (A), DX_03.1 (K)
unnamed: D108.2 (A), RDL_E1.2
unnamed: D109.2 (A), RDL_E2.2
unnamed: D123.1 (K), D124.1 (K), D125.1 (K), D126.1 (K), D127.1 (K), D128.1 (K), D129.1 (K), D130.1 (K), D131.1 (K), D132.1 (K), D133.1 (K), D134.1 (K), D135.1 (K), D136.1 (K), DM_00.2 (A), DM_01.2 (A), DM_02.2 (A), DM_03.2 (A), DM_04.2 (A), DS_52.2 (A), DS_53.2 (A), DS_54.2 (A), DS_55.2 (A), DS_56.2 (A), DS_57.2 (A), DS_58.2 (A), DS_59.2 (A), J5.5, R10.2
unnamed: D123.2 (A), DS_03.1 (K)
unnamed: D124.2 (A), DS_16.1 (K)
unnamed: D125.2 (A), DS_29.1 (K)
unnamed: D126.2 (A), DS_42.1 (K)
unnamed: D127.2 (A), DM_09.1 (K)
unnamed: D128.2 (A), DM_22.1 (K)
unnamed: D129.2 (A), DM_35.1 (K)
unnamed: D130.2 (A), DM_48.1 (K)
unnamed: D131.2 (A), DH_01.1 (K)
unnamed: D132.2 (A), DP_02.1 (K)
unnamed: D133.2 (A), DCF_03.1 (K)
unnamed: D134.2 (A), DX_04.1 (K)
unnamed: D135.2 (A), RDL_F1.2
unnamed: D136.2 (A), RDL_F2.2
unnamed: D150.1 (K), D151.1 (K), D152.1 (K), D153.1 (K), D154.1 (K), D155.1 (K), D156.1 (K), D157.1 (K), D158.1 (K), D159.1 (K), D160.1 (K), D161.1 (K), D162.1 (K), D163.1 (K), DM_05.2 (A), DM_06.2 (A), DM_07.2 (A), DM_08.2 (A), DM_09.2 (A), DM_10.2 (A), DM_11.2 (A), DM_12.2 (A), DM_13.2 (A), DM_14.2 (A), DM_15.2 (A), DM_16.2 (A), DM_17.2 (A), J5.6, R11.2
unnamed: D150.2 (A), DS_04.1 (K)
unnamed: D151.2 (A), DS_17.1 (K)
unnamed: D152.2 (A), DS_30.1 (K)
unnamed: D153.2 (A), DS_43.1 (K)
unnamed: D154.2 (A), DS_56.1 (K)
unnamed: D155.2 (A), DM_23.1 (K)
unnamed: D156.2 (A), DM_36.1 (K)
unnamed: D157.2 (A), DM_49.1 (K)
unnamed: D158.2 (A), DH_02.1 (K)
unnamed: D159.2 (A), DP_03.1 (K)
unnamed: D160.2 (A), DCF_04.1 (K)
unnamed: D161.2 (A), DX_05.1 (K)
unnamed: D162.2 (A), RDL_G1.2
unnamed: D163.2 (A), RDL_G2.2
unnamed: D177.1 (K), D178.1 (K), D179.1 (K), D180.1 (K), D181.1 (K), D182.1 (K), D183.1 (K), D184.1 (K), D185.1 (K), D186.1 (K), D187.1 (K), D188.1 (K), D189.1 (K), D190.1 (K), DM_18.2 (A), DM_19.2 (A), DM_20.2 (A), DM_21.2 (A), DM_22.2 (A), DM_23.2 (A), DM_24.2 (A), DM_25.2 (A), DM_26.2 (A), DM_27.2 (A), DM_28.2 (A), DM_29.2 (A), DM_30.2 (A), J5.7, R12.2
unnamed: D177.2 (A), DS_05.1 (K)
unnamed: D178.2 (A), DS_18.1 (K)
unnamed: D179.2 (A), DS_31.1 (K)
unnamed: D180.2 (A), DS_44.1 (K)
unnamed: D181.2 (A), DS_57.1 (K)
unnamed: D182.2 (A), DM_10.1 (K)
unnamed: D183.2 (A), DM_37.1 (K)
unnamed: D184.2 (A), DM_50.1 (K)
unnamed: D185.2 (A), DH_03.1 (K)
unnamed: D186.2 (A), DP_04.1 (K)
unnamed: D187.2 (A), DCF_05.1 (K)
unnamed: D188.2 (A), DX_06.1 (K)
unnamed: D189.2 (A), RDR_A1.2
unnamed: D190.2 (A), RDR_A2.2
unnamed: D204.1 (K), D205.1 (K), D206.1 (K), D207.1 (K), D208.1 (K), D209.1 (K), D210.1 (K), D211.1 (K), D212.1 (K), D213.1 (K), D214.1 (K), D215.1 (K), D216.1 (K), D217.1 (K), DM_31.2 (A), DM_32.2 (A), DM_33.2 (A), DM_34.2 (A), DM_35.2 (A), DM_36.2 (A), DM_37.2 (A), DM_38.2 (A), DM_39.2 (A), DM_40.2 (A), DM_41.2 (A), DM_42.2 (A), DM_43.2 (A), J5.8, R13.2
unnamed: D204.2 (A), DS_06.1 (K)
unnamed: D205.2 (A), DS_19.1 (K)
unnamed: D206.2 (A), DS_32.1 (K)
unnamed: D207.2 (A), DS_45.1 (K)
unnamed: D208.2 (A), DS_58.1 (K)
unnamed: D209.2 (A), DM_11.1 (K)
unnamed: D210.2 (A), DM_24.1 (K)
unnamed: D211.2 (A), DM_51.1 (K)
unnamed: D212.2 (A), DH_04.1 (K)
unnamed: D213.2 (A), DP_05.1 (K)
unnamed: D214.2 (A), DCF_06.1 (K)
unnamed: D215.2 (A), DX_07.1 (K)
unnamed: D216.2 (A), RDR_B1.2
unnamed: D217.2 (A), RDR_B2.2
unnamed: D231.1 (K), D232.1 (K), D233.1 (K), D234.1 (K), D235.1 (K), D236.1 (K), D237.1 (K), D238.1 (K), D239.1 (K), D240.1 (K), D241.1 (K), D242.1 (K), D243.1 (K), D244.1 (K), DM_44.2 (A), DM_45.2 (A), DM_46.2 (A), DM_47.2 (A), DM_48.2 (A), DM_49.2 (A), DM_50.2 (A), DM_51.2 (A), DM_52.2 (A), DM_53.2 (A), DM_54.2 (A), DM_55.2 (A), DM_56.2 (A), J5.9, R14.2
unnamed: D231.2 (A), DS_07.1 (K)
unnamed: D232.2 (A), DS_20.1 (K)
unnamed: D233.2 (A), DS_33.1 (K)
unnamed: D234.2 (A), DS_46.1 (K)
unnamed: D235.2 (A), DS_59.1 (K)
unnamed: D236.2 (A), DM_12.1 (K)
unnamed: D237.2 (A), DM_25.1 (K)
unnamed: D238.2 (A), DM_38.1 (K)
unnamed: D239.2 (A), DH_05.1 (K)
unnamed: D240.2 (A), DP_06.1 (K)
unnamed: D241.2 (A), DCF_07.1 (K)
unnamed: D242.2 (A), DX_08.1 (K)
unnamed: D243.2 (A), RDR_C1.2
unnamed: D244.2 (A), RDR_C2.2
unnamed: D258.1 (K), D259.1 (K), D260.1 (K), D261.1 (K), D262.1 (K), D263.1 (K), D264.1 (K), D265.1 (K), D266.1 (K), D267.1 (K), D268.1 (K), D269.1 (K), D270.1 (K), D271.1 (K), DH_00.2 (A), DH_01.2 (A), DH_02.2 (A), DH_03.2 (A), DH_04.2 (A), DH_05.2 (A), DH_06.2 (A), DH_07.2 (A), DH_08.2 (A), DH_09.2 (A), DM_57.2 (A), DM_58.2 (A), DM_59.2 (A), J5.10, R15.2
unnamed: D258.2 (A), DS_08.1 (K)
unnamed: D259.2 (A), DS_21.1 (K)
unnamed: D260.2 (A), DS_34.1 (K)
unnamed: D261.2 (A), DS_47.1 (K)
unnamed: D262.2 (A), DM_00.1 (K)
unnamed: D263.2 (A), DM_13.1 (K)
unnamed: D264.2 (A), DM_26.1 (K)
unnamed: D265.2 (A), DM_39.1 (K)
unnamed: D266.2 (A), DM_52.1 (K)
unnamed: D267.2 (A), DP_07.1 (K)
unnamed: D268.2 (A), DCF_08.1 (K)
unnamed: D269.2 (A), DX_09.1 (K)
unnamed: D270.2 (A), RDR_D1.2
unnamed: D271.2 (A), RDR_D2.2
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

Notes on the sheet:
> RX
GND
< FIX
SDA
< TX
> EN
SCL
SQW
< PPS
< 3.3V
> VBAT
> VIN

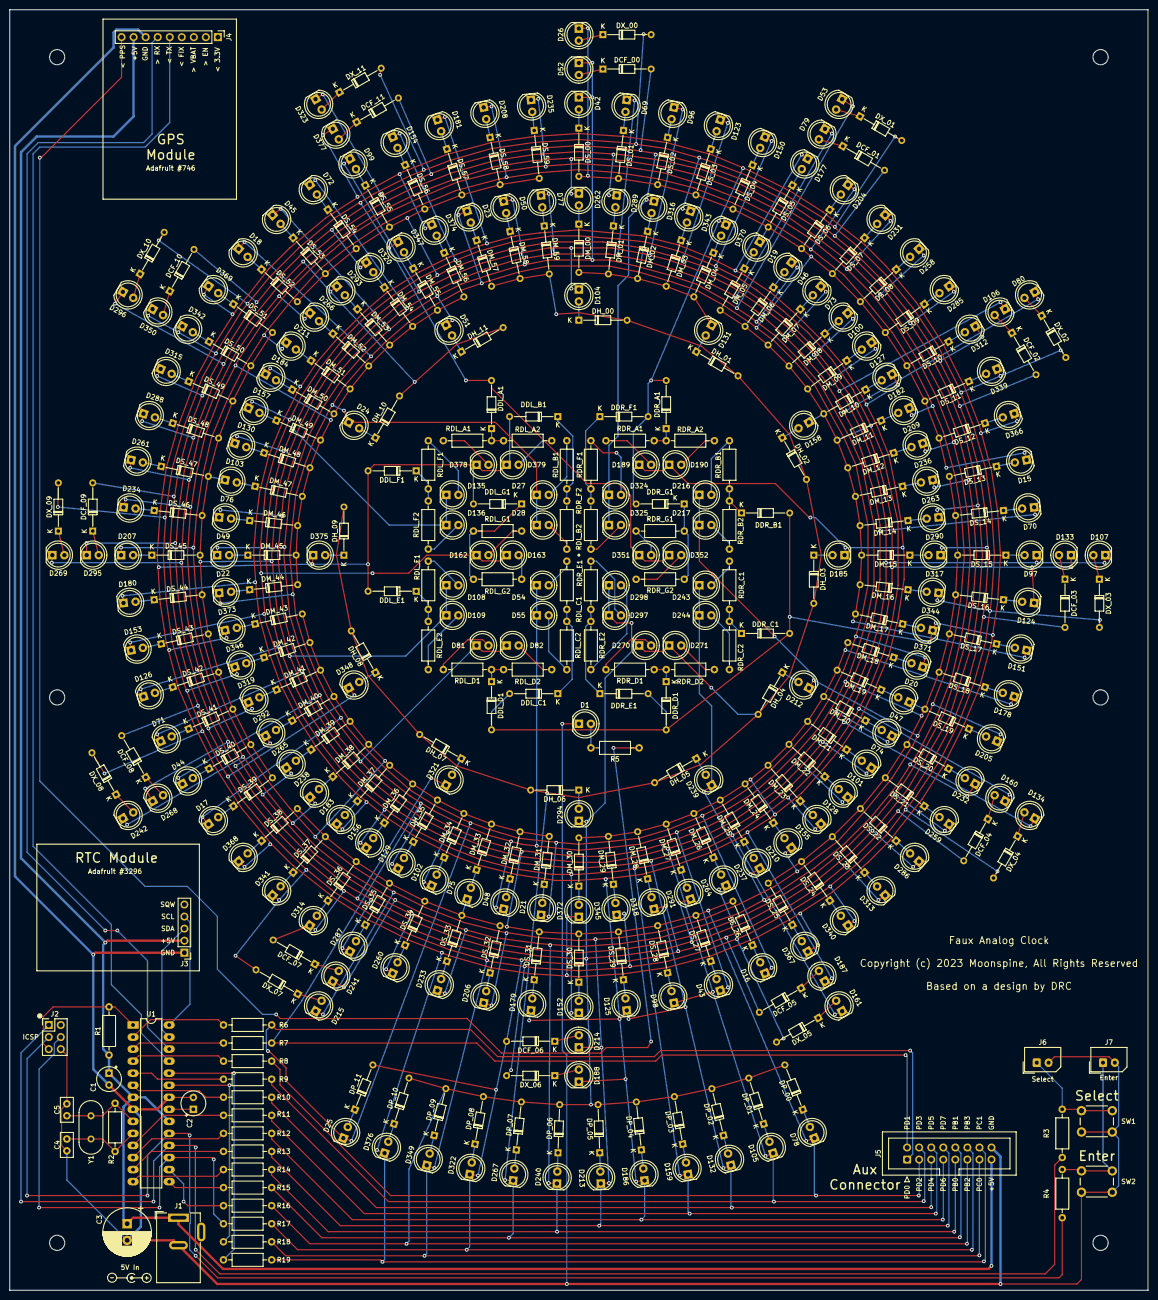
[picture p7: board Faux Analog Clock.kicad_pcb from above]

Board: 2 copper layers, 240.0 x 270.0 mm, 442 parts (0 on the bottom side), 254 nets.

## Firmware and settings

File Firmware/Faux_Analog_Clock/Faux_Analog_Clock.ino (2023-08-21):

#include "ClockDisplay.h"
#include "Timekeeper.h"
#include "ClockFace.h"
#include "ClockOptions.h"
#include "SevenSegment.h"
#include "ClockMenu.h"
#include "ClockFrameBuffers.h"
#include "ClockDisplayMode.h"

/**
 * Faux Analog Clock
 * 
 * An analog clock composed entirely of LEDs.
 * See the KiCad schematic/board design for more info.
 * 
 * Required libraries:
 *  Adafruit RTCLib 2.1.1
 *  Adafruit BusIO 1.14.1
 *  Adafruit GPS 1.7.2
 * 
 * Pinout:
 *  RTC SDA            = PC4
 *  RTC SCL            = PC5
 *  GPS TX             = PC2
 *  GPS RX             = PC3
 *  Charlieplex 0..7   = PORTD 0..7
 *  Charlieplex 8..11  = PORTB 0..3
 *  Charlieplex 12..13 = PORTC 0..1
 *  Select Button      = PB4
 *  Enter Button       = PB5
 */

/*
 * Animation timing variables (tweak these to tweak the clock fade animations)
 */
const uint32_t CLOCK_ANIM_SECONDS_FADE_TIME = 2000;
const uint32_t CLOCK_ANIM_MINUTES_FADE_TIME = 2000;
const uint32_t CLOCK_ANIM_HOURS_FADE_TIME = 4000;
const uint32_t CLOCK_ANIM_PENDULUM_FADE_TIME = 2000;
const uint32_t CLOCK_ANIM_RING_FADE_TIME = 1500000;

/*
 * Menu configuration
 */
const uint8_t MENU_SELECT_BUTTON_MASK = 0b00010000;
const uint8_t MENU_ENTER_BUTTON_MASK = 0b00100000;
const uint32_t MENU_TIMEOUT_MS = 10000;
const uint32_t MENU_BACK_BUTTON_LONG_PRESS_MS = 1000;

/*
 * Timekeeper configuration
 */
const uint32_t TIMEKEEPER_GPS_TIME_SET_INTERVAL_SECONDS = 86400;


/*
 * Various classes which are integral to clock operation
 */
ClockDisplay clockDisplay;
ClockFrameBuffers clockFrameBuffers(clockDisplay);
Timekeeper timekeeper(A2, A3, TIMEKEEPER_GPS_TIME_SET_INTERVAL_SECONDS);

ClockOptions options;
ClockMenu menu(options, MENU_SELECT_BUTTON_MASK, MENU_ENTER_BUTTON_MASK, MENU_TIMEOUT_MS, MENU_BACK_BUTTON_LONG_PRESS_MS);

ClockDisplayMode *displayMode = new AnalogClockDisplayMode();


// Clock set animation vars
uint8_t clockSetAnimationValue = 0;
int8_t clockSetAnimationDirection = 1;


// Main initialization routine
void setup() {
  // Start the clock display
  clockDisplay.begin();

  // Start the menu
  menu.begin();

  // Check for debug display requests (holding Select or Enter on startup)
  menu.update();
  if (menu.isSelectPressed()) {
    options.setCurrentUtilityMode(UTILITY_MODE_LED_TEST_1);
    executeUtilityMode();
  } else if (menu.isEnterPressed()) {
    options.setCurrentUtilityMode(UTILITY_MODE_LED_TEST_2);
    executeUtilityMode();
  }

  // Do LED fade test
  runLEDFadeTest();

  // Initialize timing buffers
  clockFrameBuffers.getSecondBuffer()->initializeFade(CLOCK_ANIM_SECONDS_FADE_TIME, 0);
  clockFrameBuffers.getMinuteBuffer()->initializeFade(CLOCK_ANIM_MINUTES_FADE_TIME, 0);
  clockFrameBuffers.getHourBuffer()->initializeFade(CLOCK_ANIM_HOURS_FADE_TIME, 0);
  clockFrameBuffers.getPendulumBuffer()->initializeFade(CLOCK_ANIM_PENDULUM_FADE_TIME, 0);

  // Initialize face ring buffers
  clockFrameBuffers.getFaceInnerRingBuffer()->initializeFade(CLOCK_ANIM_RING_FADE_TIME, 0);
  clockFrameBuffers.getFaceInnerRingBuffer()->setAllValues(0);
  clockFrameBuffers.getFaceOuterRingBuffer()->initializeFade(CLOCK_ANIM_RING_FADE_TIME, options.getDaytimeBrightness());
  clockFrameBuffers.getFaceOuterRingBuffer()->setAllValues(options.getDaytimeBrightness());

  // Start the timekeeper
  timekeeper.begin();
  timekeeper.setTimeZone(options.getTimezone(), options.getDST());
}

// Main loop
void loop() {
  bool wasTimeSetPendingLastIteration = timekeeper.isTimeSetPending();
  timekeeper.update();

  if (timekeeper.isTimeValid()) {
    // Update time
    const DateTime &now = timekeeper.getTime();
    bool isNight = now.hour() < 6 || now.hour() > 18;
    
    // Update menu and options
    menu.update();
    uint8_t brightness = isNight ? options.getPremultipliedNightBrightness() : options.getDaytimeBrightness();
    if (options.getOptionsChanged()) {
      updateOptions(brightness);
    }
    
    // Update fade
    if (options.getFadeEffectsEnabled()) {
      clockFrameBuffers.updateFade();
    } else {
      clockFrameBuffers.accelerateFadeToEnd();
    }

    // Compute pendulum index
    uint16_t milliseconds = timekeeper.getMilliseconds();
    uint16_t pendulumOffset = ((now.second() % options.getPendulumPeriod()) * static_cast<uint16_t>(1000)) / options.getPendulumPeriod();
    uint16_t pendulumIndex = pendulumOffset + milliseconds / options.getPendulumPeriod();

    // Update time display
    displayMode->update(clockFrameBuffers, now, pendulumIndex, brightness);

    // Update clock ring animation fade targets
    updateClockRingFadeTargets(now.hour(), brightness);

    // Display menu?
    if (menu.isOpen()) {
      const char *menuText = menu.getMenuText();
      writeSevenSegmentDisplay(clockFrameBuffers.getDisplayLeftBuffer(), menuText[0], brightness);
      writeSevenSegmentDisplay(clockFrameBuffers.getDisplayRightBuffer(), menuText[1], brightness);
    } else {
      // AM/PM indicator
      if (now.isPM()) {
        writeSevenSegmentDisplay(clockFrameBuffers.getDisplayLeftBuffer(), ' ', brightness);
        writeSevenSegmentDisplay(clockFrameBuffers.getDisplayRightBuffer(), 'P', brightness);
      } else {
        writeSevenSegmentDisplay(clockFrameBuffers.getDisplayLeftBuffer(), 'A', brightness);
        writeSevenSegmentDisplay(clockFrameBuffers.getDisplayRightBuffer(), ' ', brightness);
      }
    }

    // Update the time set animation and handle its aftermath
    if (timekeeper.isTimeSetPending()) {
      // If we're actively setting the time, play the time set animation
      updateTimeSetAnimation();
    } else if (wasTimeSetPendingLastIteration) {
      // If we previously had no time set (i.e. were playing the time set animation), snap the clock rings to whatever time they should be set for
      clockSetAnimationValue = 0;
      clockSetAnimationDirection = 1;
      updateClockFaceEffectMode(brightness);
    }
  } else {
    // Animate the clock face to show that the time is being set
    updateTimeSetAnimation();
  }

  // Display the clock LEDs
  clockDisplay.display();
}

/**
 * Updates the clock with any changed options
 * 
 * @param brightness The current brightness of the clock
 */
void updateOptions(uint8_t brightness) {
  // Set timezone
  timekeeper.setTimeZone(options.getTimezone(), options.getDST());

  // Update clock face effect mode
  updateClockFaceEffectMode(brightness);

  // Update clock display mode
  delete displayMode;
  switch (options.getDisplayMode()) {
    case CLOCK_DISPLAY_MODE_BINARY:
      displayMode = new BinaryClockDisplayMode();
      break;
    case CLOCK_DISPLAY_MODE_INVERTED_ANALOG:
      displayMode = new InvertedAnalogClockDisplayMode();
      break;
    case CLOCK_DISPLAY_MODE_FILL:
      displayMode = new FillClockDisplayMode();
      break;
    case CLOCK_DISPLAY_MODE_FILL_UNFILL:
      displayMode = new FillUnfillClockDisplayMode();
      break;
    default:
    case CLOCK_DISPLAY_MODE_ANALOG:
      displayMode = new AnalogClockDisplayMode();
      break;
  }
  displayMode->initialize(clockFrameBuffers, brightness);

  // Handle utility modes
  executeUtilityMode();
}

/**
 * Handle the currently selected utility mode (if any)
 */
void executeUtilityMode() {
  switch (options.getCurrentUtilityMode()) {
    case UTILITY_MODE_RESET_TIME:
      timekeeper.resetTime();
      options.setCurrentUtilityMode(UTILITY_MODE_NONE);
      break;
    case UTILITY_MODE_LED_TEST_1:
      runLedTest1();
      break;
    case UTILITY_MODE_LED_TEST_2:
      runLedTest2();
      break;
    default:
      break;
  }
}

/**
 * Updates the clock face frame buffers to reflect the current face effect mode
 * 
 * @param brightness The current brightness of the clock
 */
void updateClockFaceEffectMode(uint8_t brightness) {
  switch (options.getFaceEffects()) {
    case FACE_EFFECTS_OUTER:
      clockFrameBuffers.getFaceInnerRingBuffer()->initializeFade(0, 0);
      clockFrameBuffers.getFaceOuterRingBuffer()->initializeFade(0, 0);
      clockFrameBuffers.getFaceInnerRingBuffer()->setAllValues(0);
      clockFrameBuffers.getFaceOuterRingBuffer()->setAllValues(brightness);
      break;
    case FACE_EFFECTS_INNER:
      clockFrameBuffers.getFaceInnerRingBuffer()->initializeFade(0, 0);
      clockFrameBuffers.getFaceOuterRingBuffer()->initializeFade(0, 0);
      clockFrameBuffers.getFaceInnerRingBuffer()->setAllValues(brightness);
      clockFrameBuffers.getFaceOuterRingBuffer()->setAllValues(0);
      break;
    case FACE_EFFECTS_BOTH:
      clockFrameBuffers.getFaceInnerRingBuffer()->initializeFade(0, 0);
      clockFrameBuffers.getFaceOuterRingBuffer()->initializeFade(0, 0);
      clockFrameBuffers.getFaceInnerRingBuffer()->setAllValues(brightness);
      clockFrameBuffers.getFaceOuterRingBuffer()->setAllValues(brightness);
      break;
    case FACE_EFFECTS_ON:
    default:
      clockFrameBuffers.getFaceInnerRingBuffer()->initializeFade(CLOCK_ANIM_RING_FADE_TIME);
      clockFrameBuffers.getFaceOuterRingBuffer()->initializeFade(CLOCK_ANIM_RING_FADE_TIME);
      updateClockRingFadeTargets(timekeeper.getTime().hour(), brightness);
      clockFrameBuffers.getFaceInnerRingBuffer()->accelerateFadeToEnd();
      clockFrameBuffers.getFaceOuterRingBuffer()->accelerateFadeToEnd();
      break;
  }
}

/**
 * Updates the animation that plays while the time is being actively set
 */
void updateTimeSetAnimation() {
  clockFrameBuffers.getFaceInnerRingBuffer()->setAllValues(255 - clockSetAnimationValue);
  clockFrameBuffers.getFaceOuterRingBuffer()->setAllValues(clockSetAnimationValue);
  clockSetAnimationValue += clockSetAnimationDirection * 2;
  if (clockSetAnimationValue == 0 || clockSetAnimationValue == 250) {
    clockSetAnimationDirection = -clockSetAnimationDirection;
  }
}

/**
 * Updates the clock ring fade targets
 * 
 * @param hour The current hour
 * @param brightness The brightness
 */
inline void updateClockRingFadeTargets(uint8_t hour, uint8_t brightness) {
    clockFrameBuffers.getFaceInnerRingBuffer()->setFadeTarget(multiplyBrightness(pgm_read_byte(FACE_INNER_HOURLY_BRIGHTNESS + hour), brightness));
    clockFrameBuffers.getFaceOuterRingBuffer()->setFadeTarget(multiplyBrightness(pgm_read_byte(FACE_OUTER_HOURLY_BRIGHTNESS + hour), brightness));
}

/**
 * Multiplies the given value by the given brightness
 */
inline uint8_t multiplyBrightness(uint8_t value, uint8_t brightness) {
  return static_cast<uint8_t>(static_cast<uint16_t>(value) * static_cast<uint16_t>(brightness) / static_cast<uint16_t>(255));
}


/**
 * A sort of self-test which fades all of the LEDs in and out
 */
void runLEDFadeTest() {
  for (uint16_t i = 0; i < 256; i += 4) {
    clockDisplay.setAllLEDValues(static_cast<uint8_t>(i));
    clockDisplay.display();
  }
  clockDisplay.setAllLEDValues(255);
  for (uint16_t i = 0; i < 60; ++i) {
    clockDisplay.display();
  }
  for (uint16_t i = 0; i < 256; i += 4) {
    clockDisplay.setAllLEDValues(255 - static_cast<uint8_t>(i));
    clockDisplay.display();
  }
  clockDisplay.setAllLEDValues(0);
}

/**
 * LED test 1 - Show all LEDs at full intensity
 */
void runLedTest1() {
  clockDisplay.setAllLEDValues(255);
  while (options.getCurrentUtilityMode() != UTILITY_MODE_NONE) {
    menu.update();
    clockDisplay.display();
  }
  clockDisplay.setAllLEDValues(0);
}

/**
 * LED test 2 - Show each LED at full intensity in sequence
 */
void runLedTest2() {
  uint8_t i = 0;
  uint16_t timer = 0;
  clockDisplay.setAllLEDValues(0);
  clockDisplay.setLEDValue(i, 255);
  while (options.getCurrentUtilityMode() != UTILITY_MODE_NONE) {
    menu.update();
    clockDisplay.display();

    ++timer;
    if (timer >= 1024) {
      clockDisplay.setLEDValue(i, 0);
      i = (i + 1) % CLOCK_DISPLAY_LED_COUNT;
      clockDisplay.setLEDValue(i, 255);
      timer = 0;
    }
  }
  clockDisplay.setAllLEDValues(0);
}

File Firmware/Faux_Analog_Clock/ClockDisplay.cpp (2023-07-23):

#include "Arduino.h"
#include "FrameBufferView.h"
#include "ClockDisplay.h"

#define NOP __asm__ __volatile__ ("nop\n\t")

const uint8_t CLOCK_DISPLAY_PORTB_MASK = 0b00001111;
const uint8_t CLOCK_DISPLAY_PORTC_MASK = 0b00000011;

const uint8_t PIN_MASKS[CLOCK_DISPLAY_PIN_COUNT] = {
  0b00000001,
  0b00000010,
  0b00000100,
  0b00001000,
  0b00010000,
  0b00100000,
  0b01000000,
  0b10000000,
  0b00000001,
  0b00000010,
  0b00000100,
  0b00001000,
  0b00000001,
  0b00000010
};

ClockDisplay::ClockDisplay() {
  for (uint8_t i = 0; i < CLOCK_DISPLAY_LED_COUNT; ++i) {
    frameBuffer[i] = 0;
  }
}

void ClockDisplay::begin() {
  DDRD = 0;
  PORTD = 0;
  DDRB &= ~CLOCK_DISPLAY_PORTB_MASK;
  PORTB &= ~CLOCK_DISPLAY_PORTB_MASK;
  DDRC &= ~CLOCK_DISPLAY_PORTC_MASK;
  PORTC &= ~CLOCK_DISPLAY_PORTC_MASK;
}


void ClockDisplay::display() {
  uint8_t ledIndex = 0;
  for (uint8_t pos = 0; pos < CLOCK_DISPLAY_PIN_COUNT; ++pos) {
    // Set positive Charlieplex line
    uint8_t posMask = PIN_MASKS[pos];
    if (pos < 8) {
      DDRD = posMask;
      PORTD = posMask;
    } else if (pos < 12) {
      DDRB |= posMask;
      PORTB |= posMask;
    } else {
      DDRC |= posMask;
      PORTC |= posMask;
    }

    for (uint8_t neg = 0; neg < CLOCK_DISPLAY_PIN_COUNT; ++neg) {
      // There's obviously no LED that has both leads connected to the same line, so skip this case
      if (pos != neg) {
        uint8_t ledValue = frameBuffer[ledIndex];

        // No need to toggle any lines if the LED is off (this does change the timing a bit, but it's fine)
        if (ledValue > 0) {
          // Set negative Charlieplex line (output should already be low)
          uint8_t negMask = PIN_MASKS[neg];
          if (neg < 8) {
            DDRD |= negMask;
          } else if (neg < 12) {
            DDRB |= negMask;
          } else {
            DDRC |= negMask;
          }
        
          // On Delay
          timedWait(ledValue);

          // Clear negative Charlieplex line
          negMask = ~negMask;
          if (neg < 8) {
            DDRD &= negMask;
          } else if (neg < 12) {
            DDRB &= negMask;
          } else {
            DDRC &= negMask;
          }

          // Off delay
          if (ledValue < 255) {
            timedWait(255 - ledValue);
          }
        }

        // Move to the next LED
        ++ledIndex;
      }
    }

    // Clear positive Charlieplex line
    posMask = ~posMask;
    if (pos < 8) {
      PORTD &= posMask;
      DDRD &= posMask;
    } else if (pos < 12) {
      PORTB &= posMask;
      DDRB &= posMask;
    } else {
      PORTC &= posMask;
      DDRC &= posMask;
    }
  }
}

void ClockDisplay::setLEDValue(uint8_t index, uint8_t value) {
  if (index < CLOCK_DISPLAY_LED_COUNT) {
    frameBuffer[index] = value;
  }
}

void ClockDisplay::setLEDValues(uint8_t *source, uint8_t destIndex, uint8_t count) {
  uint8_t realCount = destIndex >= CLOCK_DISPLAY_LED_COUNT ? 0 : min(CLOCK_DISPLAY_LED_COUNT - destIndex, count);
  if (realCount > 0) {
    memcpy(frameBuffer + destIndex, source, realCount);
  }
}

void ClockDisplay::setAllLEDValues(uint8_t value) {
  memset(frameBuffer, value, CLOCK_DISPLAY_LED_COUNT);
}

FrameBufferView *ClockDisplay::newFrameBufferView(uint8_t startIndex, uint8_t count) {
  uint8_t realStartIndex = min(startIndex, CLOCK_DISPLAY_LED_COUNT - 1);
  uint8_t realCount = min(count, CLOCK_DISPLAY_LED_COUNT - realStartIndex);
  return new FrameBufferView(frameBuffer + realStartIndex, realCount);
}


void ClockDisplay::timedWait(uint8_t timeFrame) {
  // 15 ms scan at a delay length of 1 NOP
  // 18 ms scan at a delay length of 2 NOPs
  // 21 ms scan at a delay length of 3 NOPs
  // Basically 15 ms + 3 ms * (NOPs - 1)
  for (uint8_t i = 0; i < timeFrame; ++i) {
    NOP; NOP; NOP;
  }
}

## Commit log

2023-07-20 Fixed issue with outer rings when setting time
    [Faux_Analog_Clock.ino]
2023-07-24 Added fill 1, fill 2, inverted analog display modes
    [Faux_Analog_Clock.ino]
2023-07-24 Fixed clock ring snap bug
    [Faux_Analog_Clock.ino]
2023-08-07 Resistor values tweaked
    [Faux Analog Clock.kicad_sch]
2023-08-15 Reset GPS if it doesn't achieve a fix within 15 minutes
    [Timekeeper.cpp]

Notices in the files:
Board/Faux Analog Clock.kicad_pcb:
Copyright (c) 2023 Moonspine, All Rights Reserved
